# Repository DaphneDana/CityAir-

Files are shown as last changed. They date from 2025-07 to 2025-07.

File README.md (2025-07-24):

# CityAir+

**Community-Based Real-Time Carbon Emission Monitoring and Response System**

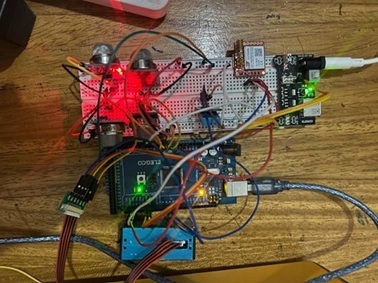
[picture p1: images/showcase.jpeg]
Dashboard Preview


## Overview

CityAir+ is a proactive, IoT-driven air quality monitoring system designed for urban communities in Eastern and Southern Africa. By combining carbon emission sensors, visual public alerts (LEDs/screens), cloud analytics, and citizen feedback, it empowers residents and governments to respond in real time to harmful pollution events. The system enhances public health and supports climate adaptation goals aligned with SDG 11 and 13.

## Monitored Parameters

| Parameter | Sensor | Range | Health Significance |
|---|---|---|---|
| Carbon Monoxide | MQ-135 | 0 – 1000 ppm | Critical safety parameter for worker exposure |
| VOC Index | MQ-2/4/9 | 0 – 1000 ppm | Industrial solvent and chemical emissions |
| Methane | MQ-4 | 0 – 5000 ppm | Explosion hazard monitoring |
| PM₂.₅ / PM₁₀ | PMS5003  | 0 – 1000 µg m⁻³ | Respiratory health indicators |
| Temperature & Humidity | DHT11 | 0 – 50 °C / 20 – 90% RH | Workplace comfort and equipment conditions  |

## Architecture

### Hardware Components
- **Edge Node**: Arduino Mega 2560 with integrated sensors
- **Connectivity**: SIM800 GSM module for cellular data transmission
- **Local Alerts**: On-site buzzer and tri-color LED indicators
- **Redundancy**: SD card data buffering to prevent data loss

### Software Stack
- **Backend**: Node.js/Express API with Prisma ORM
- **Frontend**: Responsive Next.js 14 dashboard
- **Authentication**: JWT-based role-based access control
- **Data Storage**: PostgreSQL with time-series optimization

## Key Features

- **Real-time Monitoring**: Live sensor readings updated every 30 seconds
- **Critical Alerts**: 5-second response time for hazardous conditions with multi-channel notifications
- **Data Integrity**: Store-and-forward architecture ensures no data loss during connectivity issues
- **Advanced Analytics**: Historical trends, correlation analysis, and customizable reports
- **Compliance Ready**: Automatic PDF report generation for regulatory submissions
- **DevOps Integration**: Complete CI/CD pipeline from GitHub to Vercel with automated testing
- **Enterprise Security**: Role-based access control with comprehensive audit logging
- **Community Alerts**: LEDs and public screens indicate emission levels
-  **Citizen Engagement**: People can report emissions and suggest action
-  **Government Accountability**: System logs interventions and response times

## Impact Objectives

- Provide communities and city authorities with 24/7 emission data access
- Achieve >80% public awareness through LED alerts and local screens
- Drive a 15% reduction in peak emission levels through timely action
- Empower citizen engagement via real-time feedback mechanisms

## Contributing

We welcome contributions from the community! Please follow these steps:

1. Fork the repository
2. Create a feature branch from `develop` (e.g., `feature/improved-voc-detection`)
3. Follow [Conventional Commits](https://www.conventionalcommits.org/) styling
4. Ensure all tests pass (`pnpm test` in relevant directories)
5. Maintain >80% unit test coverage for new code
6. Submit a pull request against the `develop` branch

See [CONTRIBUTING.md](CONTRIBUTING.md) for more detailed guidelines.

## Licensing

- **Firmware**: [MIT License](LICENSE-MIT.txt)
- **Dashboard/API**: [AGPL-3.0 License](LICENSE-AGPL.txt)

## Acknowledgments

This project is being developed by graduands from Makerere University and has been supported by:

- **Ubuntu Net Women Alliance 2025** 
- Makerere University – College of Computing & Informatics Technology   
- Advocacy for Digital Democracy  

## Contact

For questions or support, please contact:
- Project Lead: [project-lead@cityair+.org](mailto:project-lead@cityair+.org)
- Technical Support: [support@cityair+.org](mailto:support@cityair+.org)

---

© 2025 CityAir+

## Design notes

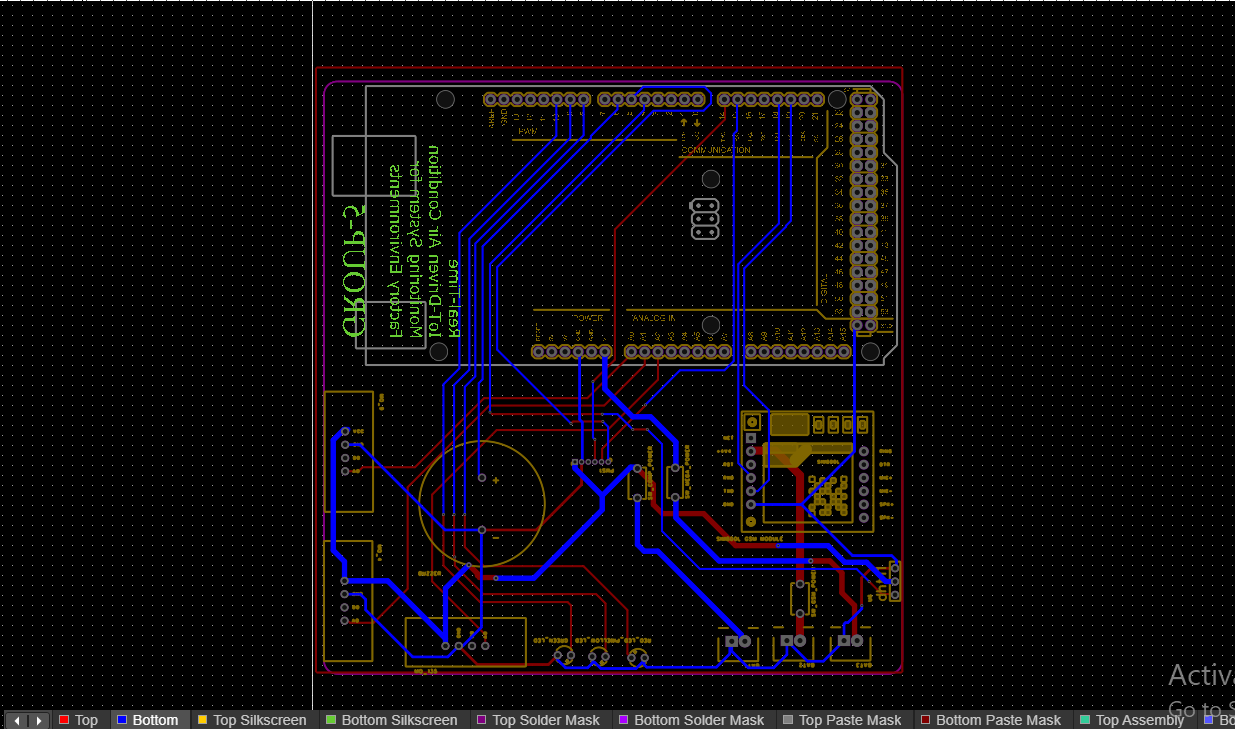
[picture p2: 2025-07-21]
hardware/pcb/PCB_Schematic.png

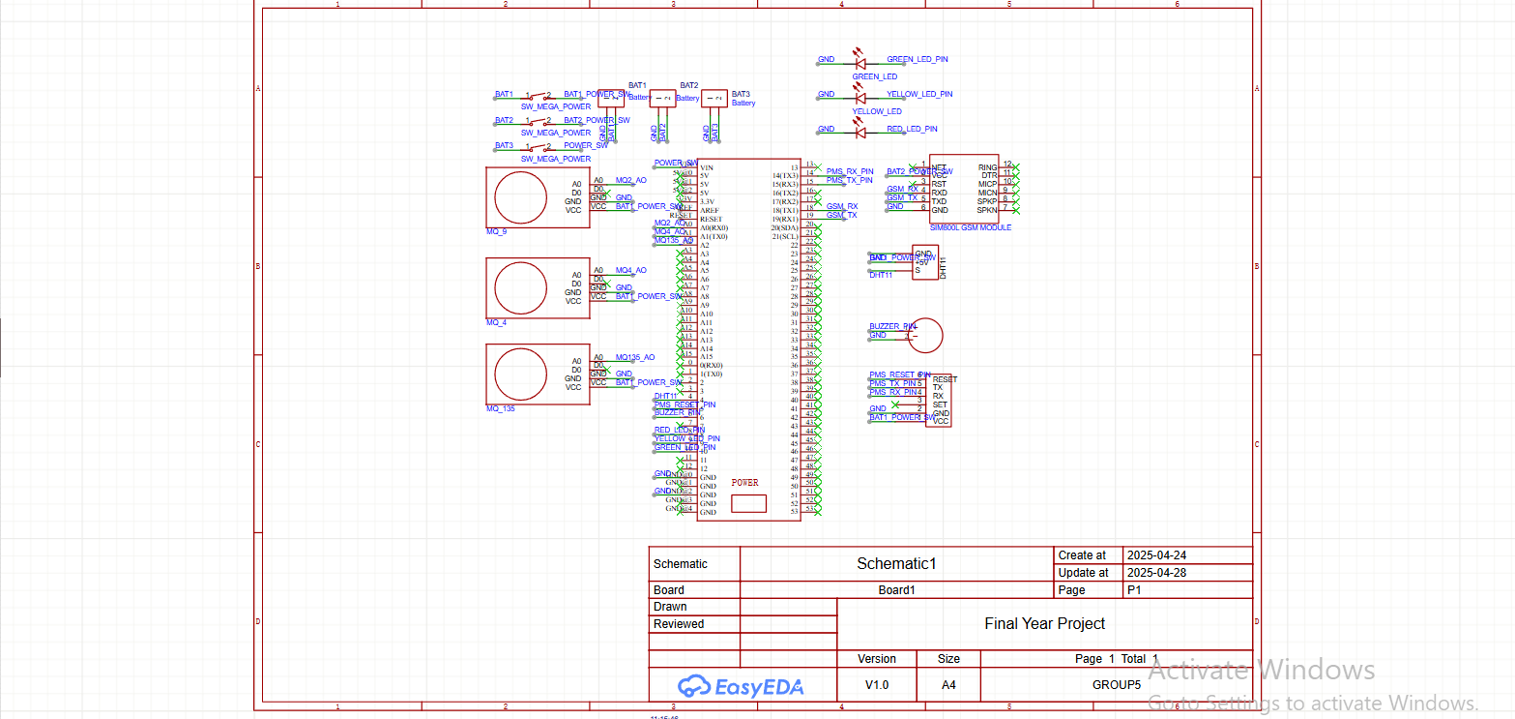
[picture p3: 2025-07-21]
hardware/schematic/Schematic.png

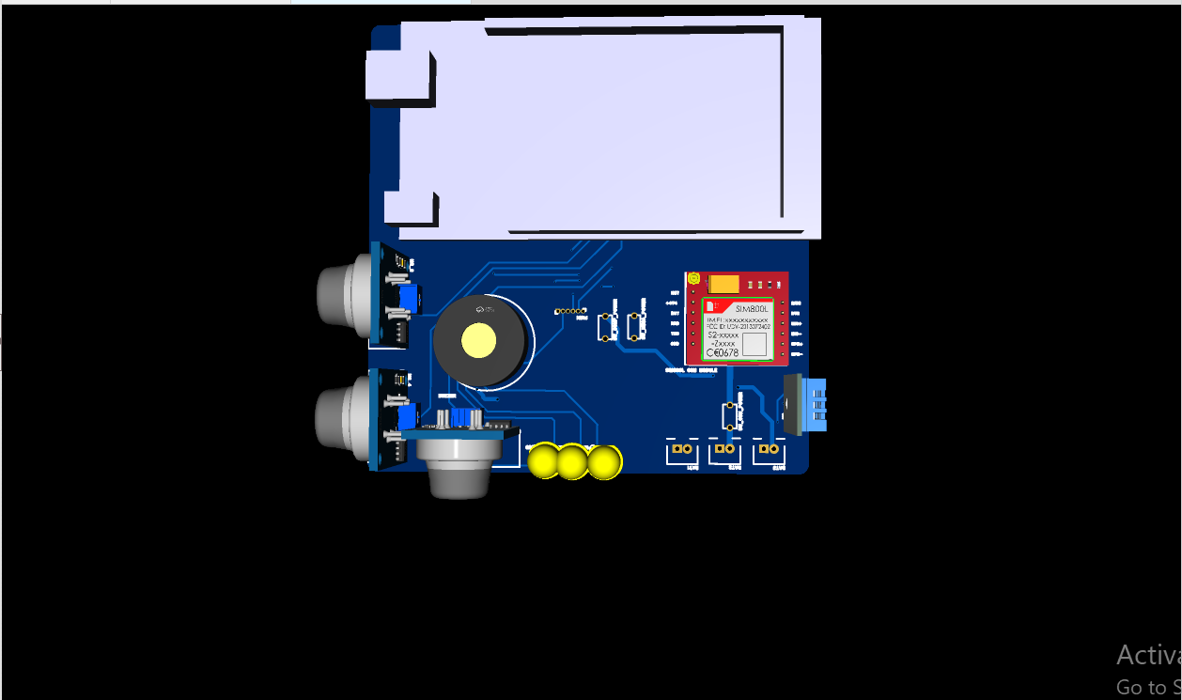
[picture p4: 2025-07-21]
hardware/pcb/PCB_3D.png

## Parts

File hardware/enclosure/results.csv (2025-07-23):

TC ID | Inputs / Preconditions | Test Area | Test Case Description | Expected Outcome | Result
TC-F-PMS | Matchbox smoke directed at PMS5003 for ≤3 s | Sensor Inputs | Verify particulate alert chain | Red LED & buzzer <5 s; dashboard PM10 critical | Pass
TC-F-CO | Attach 50 ppm CO span-gas tube to MQ-135 | Sensor Inputs | Verify carbon-monoxide alert chain | Same visual/audible alerts; CO metric red | Pass
TC-DB | Send duplicate REST POST of identical payload | Data Integrity | Attempt double insert into DB | Only one row persists; no UI duplication | Pass
TC-GSM | Unscrew GSM antenna for 10 min then re-attach | Connectivity | Evaluate offline cache & resend | “Offline” LED; data back-filled in order | Pass w/Remarks
TC-STAB | Continuous mains power for 10 h | Reliability | Long-run soak test | No resets; <5 % heap growth; 0 missed samples | Fail
TC-UI | Chrome desktop; valid admin creds | Usability | Login → live view → PDF export | All steps ≤4 clicks; PDF <20 s | Pass
TC-LED-ERR | Inject 4 V brown-out on 5 V rail | Hardware Fail-safe | Observe alert lighting under low voltage | Amber warning; sampling continues | Fail
TC-TIMEZONE | Browser UTC-05:00 | Time Handling | View timestamps in UI | UI shows local TZ; DB remains UTC | Pass w/Remarks
TC-AUTH-LOGIN | Valid admin email/password | Authentication | Standard login flow | Redirect to /dashboard; JWT issued | Pass
TC-AUTH-LOCK | Five wrong passwords | Authentication | Account lockout policy | Lock 15 min; toast message shown | Pass
TC-LIVE-REFRESH | Dashboard open 2 min | Dashboard | Auto-refresh of metric cards | Cards update every 30 s | Pass
TC-CONF-THRESH | Edit PM2.5 critical → 80 µg m⁻³ | Configuration | Threshold update workflow | New limit active next cycle; audit logged | Pass
TC-ALERT-ACK | Red alert active | Alert Flow | Acknowledge alert in UI | Status → Cleared; red LED stops | Pass
TC-PDF-REPORT | Select 24 h date range | Reporting | Generate compliance PDF | Branded PDF downloads <20 s | Pass
TC-ANAL-7DAY | 7 days of data present | Analytics | Load long-term trend & zoom | Chart renders; extrema accurate | Pass
TC-RBAC | Viewer role logged in | Security | Attempt threshold edits | “Forbidden” modal; no DB change | Pass
TC-SEC-LOGOUT | Authenticated session then logout | Security | Back-button cache check | Back shows /login; no data visible | Pass
TC-MOB-UI | Android Chrome 320 px width | Responsiveness | Inspect mobile layout | No horizontal scroll; cards stack | Pass
TC-PERF-PAINT | Chrome dev-tools 3 G throttle | Performance | Measure first paint | Dashboard first paint <2 s | Fail
TC-BE-DBFAIL | Stop MySQL for 2 min | Backend Resilience | API behaviour on DB outage | API 503; recovers automatically | Pass
TC-USER-ADD | Admin panel open | Admin Ops | Create Operator account | Account created; invite email queued | Pass
TC-PWR-LOW | Backup battery at 15 % | Power | Low-battery mode behaviour | Sample interval stretches; UI banner | Pass
TC-NET-RECOVER | Disable GSM 5 min & generate data | Network | Back-fill order & integrity | All queued samples upload intact | Pass
TC-CAL-CO | 200 ppm span gas with CAL cap | Calibration | CO span routine | New slope stored; reading ±5 ppm | Pass
TC-CAL-ZERO | Blank zero cap installed | Calibration | Zero-check all sensors | All pollutants <5 % of spec | Pass
TC-UI-TABNAV | Keyboard-only navigation | Accessibility | Tab/Shift-Tab through UI | All controls reachable; focus visible | Pass
TC-REP-SCHED | Admin schedules daily email | Automation | Scheduled PDF report job | Job saved; email sent next day | Pass
TC-PWD-POLICY | Enter weak pwd “abcd” | Security | Password-complexity check | Error message; cannot save | Pass
TC-API-ERROR | Stop Node API; reload UI | Error Handling | UI response when API down | “Service Unavailable” banner | Fail
TC-UI-DARKMODE | Toggle dark-mode switch | UI Theme | Theme inversion test | Colours invert; readability OK | Pass

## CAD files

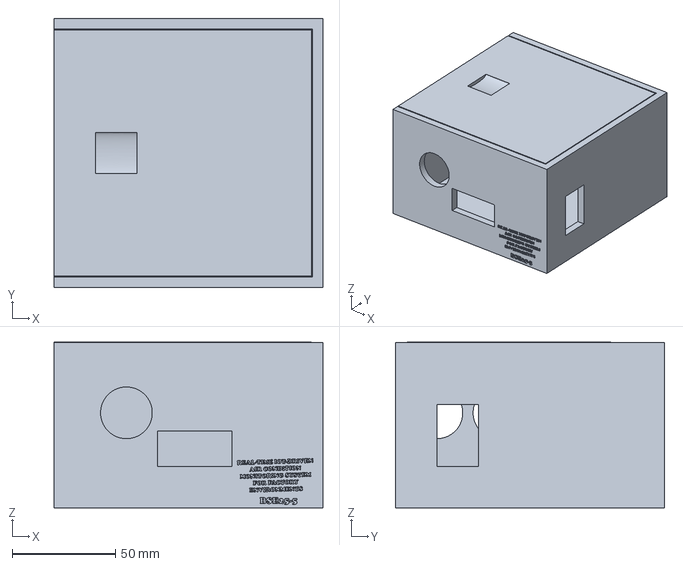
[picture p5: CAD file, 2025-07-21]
hardware/enclosure/Final Year Project v2.3mf
130.0 x 130.0 x 80.0 mm

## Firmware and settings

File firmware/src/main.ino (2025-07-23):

/**
 * Environmental Monitoring System with SOLID Principles
 *
 * This system uses multiple sensors to monitor environmental conditions
 * and provides alerts for dangerous conditions.
 */

#include "Config.h"
#include "DHTSensor.h"
#include "PMSSensor.h"
#include "MQSensor.h"
#include "GSMModule.h"
#include "AlertSystem.h"

// Create sensor instances
DHTSensor dhtSensor(Pins::DHT_PIN, DHT11);  // Change to DHT22 if using that sensor
PMSSensor pmsSensor(&SerialPorts::PMS_SERIAL, Pins::PMS_RESET_PIN);

// MQ gas sensors
MQSensor mq135Sensor(Pins::MQ135_PIN, SensorType::AIR_QUALITY, "MQ135");
MQSensor mq2Sensor(Pins::MQ2_PIN, SensorType::COMBUSTIBLE_GAS, "MQ2");
MQSensor mq4Sensor(Pins::MQ4_PIN, SensorType::METHANE, "MQ4");
MQSensor mq9Sensor(Pins::MQ9_PIN, SensorType::CO, "MQ9");

// GSM module for communications
GSMModule gsmModule(&SerialPorts::GSM_SERIAL, "internet",
                  ThingSpeakConfig::API_KEY,
                  AlertConfig::ALERT_PHONE_NUMBER);

// Alert system
AlertSystem alertSystem(Pins::GREEN_LED_PIN, Pins::YELLOW_LED_PIN,
                      Pins::RED_LED_PIN, Pins::BUZZER_PIN, &gsmModule);

// Timing variables
unsigned long lastSendTime = 0;

void setup() {
  // Initialize serial communications
  Serial.begin(115200);

  // Wait for serial port to connect (needed for native USB port only)
  while (!Serial && millis() < 3000);  // Wait up to 3 seconds for serial connection

  Serial.println(F("Starting Environmental Monitoring System with SOLID principles..."));

  // Initialize sensors
  bool dhtInitialized = dhtSensor.begin();
  if (!dhtInitialized) {
    Serial.println(F("WARNING: Failed to initialize DHT sensor"));
  }

  // Initialize PMS serial port
  SerialPorts::PMS_SERIAL.begin(9600);
  bool pmsInitialized = pmsSensor.begin();
  if (!pmsInitialized) {
    Serial.println(F("WARNING: Failed to initialize PMS sensor"));
  }

  // Initialize MQ sensors
  mq135Sensor.begin();
  mq2Sensor.begin();
  mq4Sensor.begin();
  mq9Sensor.begin();
  Serial.println(F("MQ sensors initialized"));

  // Initialize GSM serial port
  SerialPorts::GSM_SERIAL.begin(4800);
  delay(100);

  // Flash yellow LED during GSM initialization to show it's happening
  digitalWrite(Pins::GREEN_LED_PIN, LOW);
  digitalWrite(Pins::YELLOW_LED_PIN, HIGH);

  bool gsmInitialized = gsmModule.begin();
  if (!gsmInitialized) {
    Serial.println(F("WARNING: Failed to initialize GSM module"));
  }

  // Initialize alert system
  alertSystem.begin();

  Serial.println(F("System initialization complete"));
}

void loop() {
  unsigned long currentMillis = millis();

  // Update alert system indicators (highest priority)
  alertSystem.update();

  // Read all sensor data
  dhtSensor.read();
  bool pmsDataValid = pmsSensor.read();

  if (pmsDataValid) {
    pmsSensor.displayData();
  }

  mq135Sensor.read();
  mq2Sensor.read();
  mq4Sensor.read();
  mq9Sensor.read();

  // Display MQ sensor readings
  Serial.print(F("MQ135: ")); Serial.print(mq135Sensor.getValue());
  Serial.print(F(" | MQ2: ")); Serial.print(mq2Sensor.getValue());
  Serial.print(F(" | MQ4: ")); Serial.print(mq4Sensor.getValue());
  Serial.print(F(" | MQ9: ")); Serial.print(mq9Sensor.getValue());
  Serial.println();

  // Check for alerts based on the latest readings
  alertSystem.checkAlerts(
    dhtSensor.getTemperature(),
    dhtSensor.getHumidity(),
    mq135Sensor.getValue(),
    mq2Sensor.getValue(),
    mq4Sensor.getValue(),
    mq9Sensor.getValue(),
    pmsSensor.getPM25(),
    pmsSensor.getPM10(),
    pmsDataValid
  );

  // Send data at the specified interval (lowest priority)
  if (currentMillis - lastSendTime >= Timing::DATA_SEND_INTERVAL) {
    lastSendTime = currentMillis;

    // Flash yellow LED to indicate data transmission
    digitalWrite(Pins::GREEN_LED_PIN, LOW);
    digitalWrite(Pins::YELLOW_LED_PIN, HIGH);

    gsmModule.publishData(
      dhtSensor.getTemperature(),
      dhtSensor.getHumidity(),
      mq135Sensor.getValue(),
      mq2Sensor.getValue(),
      mq4Sensor.getValue(),
      mq9Sensor.getValue(),
      pmsSensor.getPM25(),
      pmsSensor.getPM10(),
      pmsDataValid
    );

    // Restore LEDs based on current alert level
    alertSystem.update();
  }

  // Short delay for responsiveness
  delay(50);
}

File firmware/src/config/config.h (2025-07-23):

#ifndef CONFIG_H
#define CONFIG_H

#include <Arduino_BuiltIn.h>

// Pin definitions
namespace Pins {
    // Sensors
    constexpr uint8_t DHT_PIN = 4;
    constexpr uint8_t PMS_RESET_PIN = 5;

    // Indicators
    constexpr uint8_t GREEN_LED_PIN = 47;
    constexpr uint8_t YELLOW_LED_PIN = 53;
    constexpr uint8_t RED_LED_PIN = 49;
    constexpr uint8_t BUZZER_PIN = 6;

    // MQ Sensors
    constexpr uint8_t MQ135_PIN = A3;  // Air quality
    constexpr uint8_t MQ2_PIN = A1;    // Combustible gas
    constexpr uint8_t MQ4_PIN = A0;    // Methane
    constexpr uint8_t MQ9_PIN = A2;    // CO/combustible gas
}

// Serial port definitions
namespace SerialPorts {
    #define PMS_SERIAL Serial3    // PMS5003 on Serial3 (pins 14,15)
    #define GSM_SERIAL Serial1    // GSM Module on Serial1 (pins 18,19)
}

// Timing constants
namespace Timing {
    constexpr unsigned long DATA_SEND_INTERVAL = 30000;  // Send data every 30 seconds
    constexpr unsigned long PMS_READ_TIMEOUT = 3000;     // Timeout for PMS sensor readings
    constexpr unsigned long DHT_MIN_INTERVAL = 2100;     // Minimum time between DHT readings
    constexpr unsigned long PMS_STABLE_INTERVAL = 2500;  // PMS stable mode interval
    constexpr unsigned long BUZZER_DURATION = 3000;      // Buzzer duration
    constexpr unsigned long LED_BLINK_INTERVAL = 250;    // LED blink interval
    constexpr unsigned long ALERT_COOLDOWN = 3600000;    // Alert cooldown (1 hour)
}

// Thresholds
namespace Thresholds {
    // Environmental thresholds
    constexpr float TEMP_HIGH_THRESHOLD = 30.0;
    constexpr float TEMP_LOW_THRESHOLD = 5.0;
    constexpr float HUMIDITY_HIGH_THRESHOLD = 80.0;
    constexpr float HUMIDITY_LOW_THRESHOLD = 20.0;

    // Air quality thresholds
    constexpr uint16_t PM25_THRESHOLD = 25;
    constexpr uint16_t PM10_THRESHOLD = 50;

    // Gas sensor thresholds
    constexpr int MQ135_THRESHOLD = 700;
    constexpr int MQ2_THRESHOLD = 600;
    constexpr int MQ4_THRESHOLD = 600;
    constexpr int MQ9_THRESHOLD = 600;
}

// Alert configuration
namespace AlertConfig {
    constexpr char ALERT_PHONE_NUMBER[] = "+1234567890";
}

// ThingSpeak configuration
namespace ThingSpeakConfig {
    constexpr char API_KEY[] = "XR1OCESZGWSNRVVN";
}

// Sensor types
enum class SensorType {
    TEMPERATURE,
    HUMIDITY,
    AIR_QUALITY,
    COMBUSTIBLE_GAS,
    METHANE,
    CO
};

// Alert levels
enum class AlertLevel {
    NORMAL,
    WARNING,
    CRITICAL
};

#endif // CONFIG_H

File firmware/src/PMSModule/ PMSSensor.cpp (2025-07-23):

//
// Created by HP on 07/05/2025.
//

#include "PMSSensor.h"

PMSSensor::PMSSensor(Stream* serial, uint8_t resetPin)
    : serial(serial), resetPin(resetPin), dataValid(false), failCount(0) {
    memset(&data, 0, sizeof(data));
}

bool PMSSensor::begin() {
    // Set up the reset pin
    pinMode(resetPin, OUTPUT);
    digitalWrite(resetPin, HIGH);  // Keep sensor active

    // Reset sensor to start fresh
    reset();

    // Per datasheet, wait 30 seconds for stable data after power up
    Serial.println(F("Waiting 30 seconds for PMS5003 to stabilize..."));
    unsigned long startWait = millis();
    while (millis() - startWait < 30000) {
        // Print a dot every second to show progress
        if ((millis() - startWait) % 1000 == 0) {
            Serial.print(".");
        }
        // Process any data that might arrive during wait
        clearBuffer();
        delay(50);
    }
    Serial.println(F("\nPMS5003 warm-up complete"));

    return true;
}

void PMSSensor::clearBuffer() {
    while (serial->available()) {
        serial->read();
    }
}

bool PMSSensor::read() {
    // Clear buffer first
    clearBuffer();

    // Small delay to allow new data to arrive
    delay(100);

    // Wait for data to become available
    unsigned long timeout = millis() + Timing::PMS_READ_TIMEOUT;
    while (!serial->available() && millis() < timeout) {
        delay(10);
    }

    if (!serial->available()) {
        dataValid = false;
        return false;
    }

    // Look for the start bytes (0x42, 0x4D as defined in datasheet)
    boolean foundStart = false;
    unsigned long startTimeout = millis() + 1000;

    while (!foundStart && millis() < startTimeout) {
        if (serial->peek() != 0x42) {
            serial->read(); // Skip non-start byte
            if (!serial->available()) {
                dataValid = false;
                return false;
            }
        } else {
            // We found first start byte (0x42), check for second (0x4D)
            byte startByte1 = serial->read();

            if (serial->available() && serial->peek() == 0x4D) {
                // We have a valid header!
                byte startByte2 = serial->read();
                foundStart = true;

                // Wait until we have at least 30 more bytes (32 total - 2 we already read)
                startTimeout = millis() + 1000;
                while (serial->available() < 30 && millis() < startTimeout) {
                    delay(10);
                }

                if (serial->available() < 30) {
                    Serial.print(F("Incomplete frame. Only "));
                    Serial.print(serial->available());
                    Serial.println(F(" bytes available"));
                    dataValid = false;
                    return false;
                }

                // Now read the complete data frame
                uint8_t buffer[32];

                // Put the two header bytes we already read
                buffer[0] = startByte1; // 0x42
                buffer[1] = startByte2; // 0x4D

                // Read the remaining 30 bytes
                for (int i = 2; i < 32; i++) {
                    buffer[i] = serial->read();
                }

                // Frame length check (bytes 2-3, should be 0x001C = 28)
                uint16_t frameLen = buffer[2] << 8 | buffer[3];
                if (frameLen != 0x001C) {
                    Serial.print(F("Invalid frame length: 0x"));
                    Serial.println(frameLen, HEX);
                    dataValid = false;
                    return false;
                }

                // Calculate checksum (bytes 0 to 29)
                uint16_t sum = 0;
                for (int i = 0; i < 30; i++) {
                    sum += buffer[i];
                }

                // Extract checksum from data (bytes 30-31)
                uint16_t checksum = buffer[30] << 8 | buffer[31];

                if (sum != checksum) {
                    Serial.println(F("Checksum failure - corrupted data"));
                    dataValid = false;
                    return false;
                }

                // Data is valid, parse values according to datasheet
                data.pm10_standard = buffer[4] << 8 | buffer[5];   // PM1.0 (CF=1)
                data.pm25_standard = buffer[6] << 8 | buffer[7];   // PM2.5 (CF=1)
                data.pm100_standard = buffer[8] << 8 | buffer[9];  // PM10 (CF=1)

                data.pm10_env = buffer[10] << 8 | buffer[11];      // PM1.0 (atmospheric)
                data.pm25_env = buffer[12] << 8 | buffer[13];      // PM2.5 (atmospheric)
                data.pm100_env = buffer[14] << 8 | buffer[15];     // PM10 (atmospheric)

                data.particles_03um = buffer[16] << 8 | buffer[17]; // >0.3um count
                data.particles_05um = buffer[18] << 8 | buffer[19]; // >0.5um count
                data.particles_10um = buffer[20] << 8 | buffer[21]; // >1.0um count
                data.particles_25um = buffer[22] << 8 | buffer[23]; // >2.5um count
                data.particles_50um = buffer[24] << 8 | buffer[25]; // >5.0um count
                data.particles_100um = buffer[26] << 8 | buffer[27]; // >10um count

                // Sanity check for unreasonable values - typically PM2.5 shouldn't exceed 1000
                if (data.pm25_standard > 1000 || data.pm10_standard > 2000) {
                    Serial.println(F("Data values out of expected range"));
                    dataValid = false;
                    return false;
                }

                // Success!
                dataValid = true;
                failCount = 0;
                return true;
            } else {
                // Not a valid second byte, continue searching
                if (serial->available() > 0) {
                    serial->read(); // consume the byte we peeked at
                } else {
                    dataValid = false;
                    return false; // no more data
                }
            }
        }
    }

    // If we got here, we couldn't find the start sequence
    dataValid = false;
    failCount++;

    if (failCount > 1) {
        reset();
        failCount = 0;
    }

    return false;
}

bool PMSSensor::reset() {
    Serial.println(F("Resetting PMS sensor..."));

    // Use RESET pin to hardware reset the sensor
    digitalWrite(resetPin, LOW);   // Reset the sensor
    delay(300);                    // Hold in reset for 300ms
    digitalWrite(resetPin, HIGH);  // Release from reset

    // Clear any data in the buffer
    clearBuffer();

    Serial.println(F("PMS sensor reset. Allow 30 seconds for stabilization."));
    return true;
}

bool PMSSensor::isDataValid() const {
    return dataValid;
}

SensorType PMSSensor::getType() const {
    return SensorType::AIR_QUALITY;
}

uint16_t PMSSensor::getPM25() const {
    return data.pm25_standard;
}

uint16_t PMSSensor::getPM10() const {
    return data.pm100_standard;
}
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

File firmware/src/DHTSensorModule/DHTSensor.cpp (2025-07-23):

//
// Created by mkb2001 on 07/05/2025.
//

#include "DHTSensor.h"

DHTSensor::DHTSensor(uint8_t pin, uint8_t dhtType)
    : dht(pin, dhtType), pin(pin), type(dhtType),
      lastReadTime(0), lastTemperature(25.0), lastHumidity(50.0),
      dataValid(false) {
}

bool DHTSensor::begin() {
    dht.begin();
    // Test if sensor is responding
    delay(1000); // Give DHT time to stabilize

    float t = dht.readTemperature();
    float h = dht.readHumidity();

    if (isnan(t) || isnan(h)) {
        Serial.println(F("WARNING: DHT sensor not responding!"));
        return false;
    }

    lastTemperature = t;
    lastHumidity = h;
    dataValid = true;
    lastReadTime = millis();

    Serial.print(F("DHT sensor working. Initial reading: "));
    Serial.print(t); Serial.print(F("°C, "));
    Serial.print(h); Serial.println(F("%"));

    return true;
}

bool DHTSensor::read() {
    unsigned long currentMillis = millis();

    // Only read sensor if minimum interval has elapsed
    if (currentMillis - lastReadTime >= Timing::DHT_MIN_INTERVAL) {
        lastReadTime = currentMillis;

        float temperature = dht.readTemperature();
        float humidity = dht.readHumidity();

        if (!isnan(temperature) && !isnan(humidity)) {
            lastTemperature = temperature;
            lastHumidity = humidity;
            dataValid = true;

            Serial.print(F("Temp: ")); Serial.print(temperature);
            Serial.print(F("°C | Humidity: ")); Serial.print(humidity);
            Serial.println(F("%"));

            return true;
        } else {
            Serial.println(F("Failed to read from DHT sensor."));
            Serial.print(F("Using last valid readings - Temp: "));
            Serial.print(lastTemperature);
            Serial.print(F("°C, Humidity: "));
            Serial.print(lastHumidity);
            Serial.println(F("%"));

            return false;
        }
    } else {
        Serial.print(F("Skipped DHT reading (need 2s between reads). "));
        Serial.print(F("Using last values - Temp: "));
        Serial.print(lastTemperature);
        Serial.print(F("°C, Humidity: "));
        Serial.print(lastHumidity);
        Serial.println(F("%"));

        return false;
    }
}

bool DHTSensor::isDataValid() const {
    return dataValid;
}

SensorType DHTSensor::getType() const {
    return SensorType::TEMPERATURE; // Simplification - this sensor handles both temp & humidity
}

float DHTSensor::getTemperature() const {
    return lastTemperature;
}

float DHTSensor::getHumidity() const {
    return lastHumidity;
}

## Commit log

2025-07-21 added the app and components folder
    [Final Year Project v2.3mf, results.csv]
2025-07-22 Added the landing page
2025-07-23 feat: implement real-time air quality dashboard with pollutant cards, AQI, historical trends, and filters
